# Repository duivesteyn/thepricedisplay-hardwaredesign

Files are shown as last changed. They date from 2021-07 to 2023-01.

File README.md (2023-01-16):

# thepricedisplay v2021 Hardware Design

Hardware Design and Data for making the price display hardware, pcb, case and general assembly.

Github repo created on 2021-07-11 in Adelaide.  

Also an awesome challenge, as I havent done a PCB or 3D printed before. 

Goal:
* Make initial batch of 10 price displays! See what I can get for the first few!!
* See if that works, then make 10 more!
* Unit cost needs to be less than $30!

# v2021 - First Iteration of the product** 

* The first thePriceDisplay screen with 6 items on display. 
* based upon Waveshare 2.9" ePaper Screen and an esp32 Dev Module.
* Operates on 115200 baud.

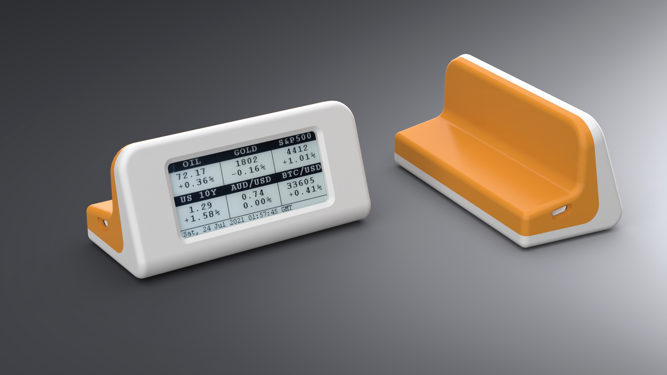
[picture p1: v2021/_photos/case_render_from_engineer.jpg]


## Design Concept
* Working Small Run Prototype
* Dev Board mounted onto custom PCB which does the translation for the wires to fit nicely. 
* No Battery. Was originally going to have a battery, however the dev boards with orthagonal JST battery connector are not available. I need the USB port to be on a seperate plain to the 2pin battery jst. (USB will extrude through case and JST should be internal). Oh well leave this for ver 2.

## BOM
| Part | Cost ea |
| ---| ---|
| waveshare screen (2.9") | $25 | 
| ESP Dev Board | $5 |
| 8 pin cable from screen to adapter board (8pin, PH (2.0) and 15cm long!) | $1 |
| Custom Adapter board PCB  ($30/10) | $3.1 |
| JST Connector which goes onto custom PCB (S8B-PH-SM4-TB) | $0.1 | 
| Case!!! | $15 |
| TOTAL | $75 |

## Assembly Instructions (v2021)
* Solder JST Connector and an 38pin ESP32 (FEIYANG) board together. See below Pins Connection for soldering guide.
* Test each connection between the JST and the ESP32 Pin!
* Prepare Case with Surface Finish and Paint!
    - Sand with 600+ grit wet/dry sandpaper, in water.
    - Use that Nice Plastic Conditioner
    - Install screen into top part of case. 

    - Connect PCB to Screen (lose PCB on ribbon cable.)
    - Program PCB with latest arduino code. Custom ID for each item! (TESTS SCREEN)
        - Serial port /dev/cu.usbserial-0001
        - Compile+upload. HOLD BOOT on BOARD for 2 secs when the Arduino Compiler says "Connecting........_____....._____." 
    - Install PCB Assembly into case. Scres are XYY and ABZ
    - Top Screen side screws:
    - Bottom Side screws: Self Tapper 1.5*4mm   with ORing below.
    - O Ring on bottom screws. (TYPE: OD2.5*0.5-20NB mm)
    - Load and stop on boot screen
    - Put in bag with USB cable.
    - Put sticker with logo on bag!

## v2021 Part Orders

BOM for 10 items:

| Part |Quantity Needed| Ordered/Have |
|---|---|---|
| Screens | 10 | 1 |
| PCB | 10 | 10 | 
| FEIYANG Board 38pin | 10 | 10 |
| PH2.0 Female Double head Connector 10cm Long, 8pin | 10 | 20 |
| JST Connector S8B-PH-SM4-TB | 20 | 20 |
| Screws 1.5mm x 5mm - Small End! (2.0mm hole) | 20 | 50 |
| Screws 2.6mm x 4mm - Screen and big end | 40 | 50 |
 
The 1.5mm (smaller) screws work great in a 2.0mm Diameter hole.
The 2.6mm screws work well in securing the screen, and the esp32 board.

## Pins Connection to Display 

The pins used on the esp32 Dev board to the Waveshare for working code are as follows:**

| Name | e-Paper Wire |  ESP32 Pin |
|---|---|---|
| VCC |  3.3V |  [Grey] |
| GND |  GND |  [Brown] |
| DIN |  GPIO14 |  [Blue] |
| CLK |  GPIO13 |  [Yellow]  |
| CS |  GPIO15 |  [Orange]  |
| DC |  GPIO27 |  [Green] |
| RST |  GPIO26 |  [White] |
| BUSY |  GPIO25 |  [Purple]  |

## Power Usage
* Sleeps most of the time. So its very power efficient.
* when updating it uses 0.04A (at 5V) using it for an hour on the PC consumed 13mah.
    - i.e. 17.5hrs of continual updating on a 700mah battery! which is only ~1-2% of the total cycle of the device! i.e. battery power is very effective.

## v2021 Device IDs
Schema: 8 digits. v1 starts with 1.
Backend DB setup for these devices!

#| n |  DeviceID  | Setup? |    Comment                          |
#|---|------------|--------|-------------------------------------|
#| T |  3b3a8397  |  ✅    | BMD Test Device                     |
#| 1 |  1a934f75  |  ✅    | READY TO GO!                        |
#| 2 |  14802ca3  |  ✅    | Gave to Gareth                      |
#| 3 |  1a49c43f  |  ✅    | Gave to Ben Broyd                   |
#| 4 |  19c4e9b5  |  ✅    | READY TO GO!                        |

# Manufacturing Notes

## Custom PCB Design Notes

Connects esp32 into a S8B-PH-SM4-TB connector. This flattens the overall design as no pins need to go vertically into the board.

Note: Font = OCR-A (same as what is used in fritzing)

PCB had a few revisions:
* ver 0.1 is my first PCB. Had a wrong connector pad. (Produced 10x)
* ver 0.2 is the one with the right connector pad. (Produced 10x)
* ver 0.3 has holes in the sides for use with Case designed with CAD engineer in August 2021.
* ver 0.4 has JST connector flipped 180deg. It reduces a fold in the cables.

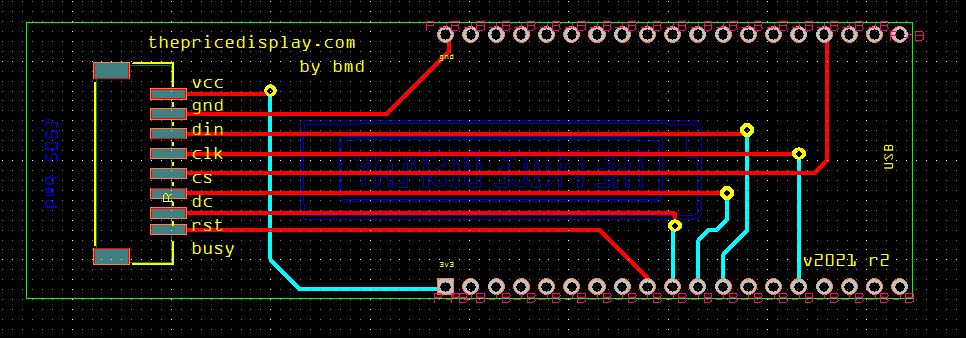
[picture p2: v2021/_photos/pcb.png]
 

## Case Design

* ver 0.0 is the version I made preemptively before I had the code working.
* ver 0.1 is the one the cad engineer made in August 2021. Designed by [janangachandima
](https://www.fiverr.com/janangachandima/design-any-enclosures-for-your-product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) on Fiverr.

## Lessons Learned
- Case too detailed. Had breakages in screw locations.
- Didnt factor in shipping etc.
- Self assembling takes forever.
- changedd color at last minute and so USB cable didnt match!

## ISSUES:
- Have ~3 boards that are bad and need reSOLDERING!!
- Have ~5 back cases that broke!!

# ROADMAP

* On Custom PCB! with esp32-wroom integrated into the board (And presoldered hopefully!!!)
* Supports battery backup
* Case design refined - better corners, and slimmer.
* PCB ver 0.4 have whole esp32 and connector on the same board!!
    * Use this [Schematic](https://learn.adafruit.com/huzzah32-esp32-breakout-board/downloads) or [This One](https://learn.adafruit.com/adafruit-huzzah32-esp32-feather/downloads)

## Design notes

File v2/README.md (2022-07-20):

# IDeas for V2!

- Design Version for Oil Price only!
- Get 3d model of device
- Create new case from 3mm acrylic sheets - and holes for screws
- Test 3d print in maker lab
- Layout pattern for laser cutter
    - Makerspace laser cutter is 720mm x 420mm
- Get screws and nuts.
- Integrate and refine
- Presets:
```
    AU: aid/usd, asx200, sap500, cba, bhp, qan
    USA: nasdaq, sap500, dow, 10y bond, aapl, goog
    UK: FTSE, other UK relevant stocks
    Oil: XOM, SLB, Hess, CvN, Brent, WTI
    Meme: TSLA, GME, AMC, Aark, COIN
    Crypto: BTC, Doge
    Gold : gold price,  top 5 biggest gold cos
    Gold AU: gold price, gold price au, newcrest, NST, WAF,
```
- Batch produce
- Render image for web! - Needs final case design. 3D Screenshot would be great!

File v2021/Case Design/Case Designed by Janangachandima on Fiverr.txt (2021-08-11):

Gig
https://www.fiverr.com/janangachandima/design-any-enclosures-for-your-product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

Link https://www.fiverr.com/v4/users/bend136i/orders/FO7197EB4F5C5?source=orders_navigator

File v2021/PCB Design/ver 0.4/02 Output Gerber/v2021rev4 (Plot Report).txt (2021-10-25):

Plot Report
-----------

Report Written:     Monday, September 20, 2021
Design Path:        C:\Users\Ben\Documents\GitHub\thepricedisplay-hardwaredesign\v2021\PCB Design\ver 0.4\01 DesignSpark PCB Work\v2021rev4.pcb
Design Title:       
Created:            6/08/2021 13:50:52
Last Saved:         20/09/2021 21:25:26
Editing Time:       601 min
Units:              mm (precision 0)

Device Settings
===============

Gerber Settings
===============

    Leading zero suppression.
    G01 assumed throughout.
    Line termination <*> <CR> <LF>.
    3.5 format absolute inches.

    Format commands defined in Gerber file.
    Aperture table defined in Gerber file.
    Hardware arcs allowed.

Plots Output
============

    Plot Job: "C:\Users\Ben\Documents\GitHub\thepricedisplay-hardwaredesign\v2021\PCB Design\ver 0.4\01 DesignSpark PCB Work\v2021rev4.mop"

Gerber Output
=============

C:\Users\Ben\Documents\GitHub\thepricedisplay-hardwaredesign\v2021\PCB Design\ver 0.4\01 DesignSpark PCB Work\v2021rev4 - Top Silkscreen.gbr

    Layers:
    ------------------
    Top Silkscreen
    Board Outlines

    D-Code Shape  (thou)
    -----------------------
    D10    Round 6.00
    D13    Round 1.00
    D25    Round 5.00

Gerber Output
=============

C:\Users\Ben\Documents\GitHub\thepricedisplay-hardwaredesign\v2021\PCB Design\ver 0.4\01 DesignSpark PCB Work\v2021rev4 - Top Paste.gbr

    Layers:
    -------------
    Top Paste

    D-Code Shape  (thou)
    -----------------------------------------------
    D14    Rectangle 56.70 X 131.70  Rotation 90
    D15    Rectangle 35.10 X 134.10  Rotation 90

Gerber Output
=============

C:\Users\Ben\Documents\GitHub\thepricedisplay-hardwaredesign\v2021\PCB Design\ver 0.4\01 DesignSpark PCB Work\v2021rev4 - Top Copper.gbr

    Layers:
    --------------
    Top Copper

    D-Code Shape  (thou)
    -----------------------------------------------
    D16    Round 15.00
    D17    Round 48.00
    D18    Rectangle 63.00 X 138.00  Rotation 90
    D19    Rectangle 39.00 X 138.00  Rotation 90
    D70    Round 61.42
    D71    Square 61.42

Gerber Output
=============

C:\Users\Ben\Documents\GitHub\thepricedisplay-hardwaredesign\v2021\PCB Design\ver 0.4\01 DesignSpark PCB Work\v2021rev4 - Top Resist.gbr

    Layers:
    --------------
    Top Resist

    D-Code Shape  (thou)
    -----------------------------------------------
    D20    Round 54.30
    D21    Rectangle 69.30 X 144.30  Rotation 90
    D22    Rectangle 45.30 X 144.30  Rotation 90
    D23    Round 67.72
    D24    Square 67.72

Gerber Output
=============

C:\Users\Ben\Documents\GitHub\thepricedisplay-hardwaredesign\v2021\PCB Design\ver 0.4\01 DesignSpark PCB Work\v2021rev4 - Bottom Copper.gbr

    Layers:
    -----------------
    Bottom Copper

    D-Code Shape  (thou)
    -----------------------
    D16    Round 15.00
    D17    Round 48.00
    D70    Round 61.42
    D71    Square 61.42

Gerber Output
=============

C:\Users\Ben\Documents\GitHub\thepricedisplay-hardwaredesign\v2021\PCB Design\ver 0.4\01 DesignSpark PCB Work\v2021rev4 - Bottom Silkscreen.gbr

    Layers:
    ---------------------
    Bottom Silkscreen
    Board Outlines

    D-Code Shape  (thou)
    -----------------------
    D13    Round 1.00
    D25    Round 5.00

Gerber Output
=============

C:\Users\Ben\Documents\GitHub\thepricedisplay-hardwaredesign\v2021\PCB Design\ver 0.4\01 DesignSpark PCB Work\v2021rev4 - Bottom Paste.gbr

    Layers:
    ----------------
    Bottom Paste

    D-Code Shape  (thou)
    -----------------------

Gerber Output
=============

C:\Users\Ben\Documents\GitHub\thepricedisplay-hardwaredesign\v2021\PCB Design\ver 0.4\01 DesignSpark PCB Work\v2021rev4 - Bottom Resist.gbr

    Layers:
    -----------------
    Bottom Resist

    D-Code Shape  (thou)
    -----------------------
    D20    Round 54.30
    D23    Round 67.72
    D24    Square 67.72

Gerber Output
=============

C:\Users\Ben\Documents\GitHub\thepricedisplay-hardwaredesign\v2021\PCB Design\ver 0.4\01 DesignSpark PCB Work\v2021rev4 - Documentation.gbr

    Layers:
    ------------------
    Documentation
    Board Outlines

    D-Code Shape  (thou)
    -----------------------
    D25    Round 5.00

Gerber Output
=============

C:\Users\Ben\Documents\GitHub\thepricedisplay-hardwaredesign\v2021\PCB Design\ver 0.4\01 DesignSpark PCB Work\v2021rev4 - Gerber Drill Data - [Through Hole].gbr

    Layers:
    ------------------
    [Through Hole]

    D-Code Shape  (thou)
    -----------------------
    D26    Round 24.00
    D27    Round 40.94

Gerber Output
=============

C:\Users\Ben\Documents\GitHub\thepricedisplay-hardwaredesign\v2021\PCB Design\ver 0.4\01 DesignSpark PCB Work\v2021rev4 - NC Drill Data - [Through Hole].gbr

    Layers:
    ------------------
    [Through Hole]

    D-Code Shape  (thou)
    -----------------------
    D26    Round 24.00
    D27    Round 40.94

Gerber Output
=============

plot.ger

    Layers:
    ------------------
    [Through Hole]

Drill Ident Drawing
===================

    Drill Plated Size Shape ID
    -----------------------------------
    24    Y      100  Round A
    41    Y      100  Round B

    D-Code Shape  (thou)
    -----------------------
    D25    Round 5.00
    D28    Round 100.00

End Of Report.

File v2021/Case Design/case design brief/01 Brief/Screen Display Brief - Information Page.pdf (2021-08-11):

## 䘀爀漀渀琀

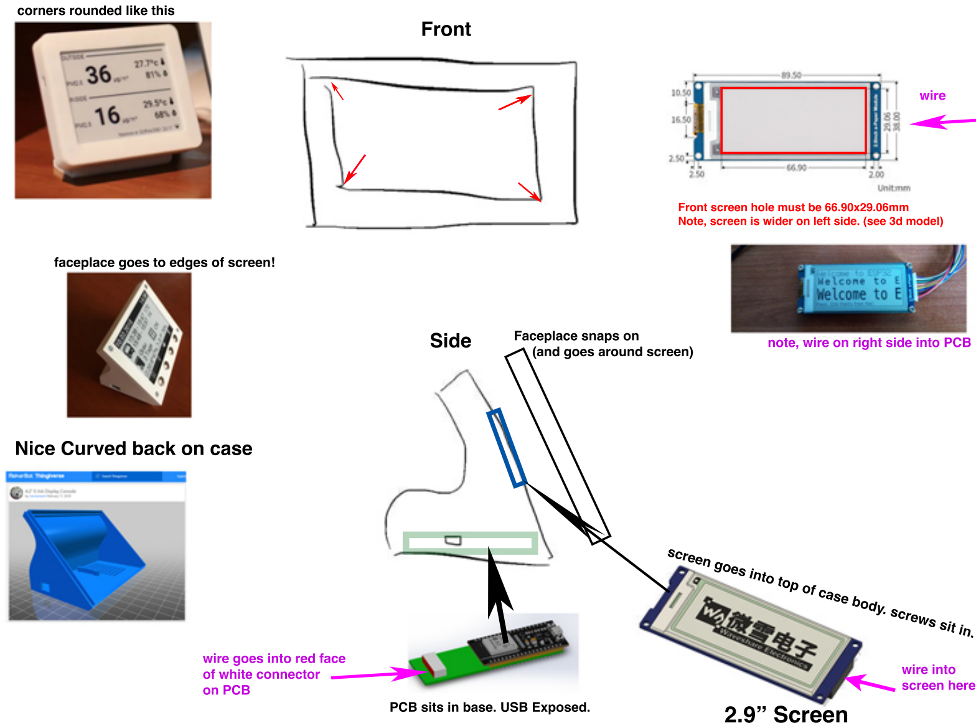
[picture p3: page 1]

## 一椀挀攀䌀甀爀瘀攀搀戀愀挀欀漀渀挀愀猀攀

## 匀椀搀攀

昀愀挀攀瀀氀愀挀攀最漀攀猀琀漀攀搀最攀猀漀昀猀挀爀攀攀渀℀

䘀愀挀攀瀀氀愀挀攀猀渀愀瀀猀漀渀
⠀愀渀搀最漀攀猀愀爀漀甀渀搀猀挀爀攀攀渀⤀

䘀爀漀渀琀猀挀爀攀攀渀栀漀氀攀洀甀猀琀戀攀㘀㘀⸀㤀　砀㈀㤀⸀　㘀洀洀 一漀琀攀Ⰰ猀挀爀攀攀渀椀猀眀椀搀攀爀漀渀氀攀昀琀猀椀搀攀⸀⠀猀攀攀㌀搀洀漀搀攀氀⤀

倀䌀䈀猀椀琀猀椀渀戀愀猀攀⸀唀匀䈀䔀砀瀀漀猀攀搀⸀

眀椀爀攀最漀攀猀椀渀琀漀爀攀搀昀愀挀攀
漀昀眀栀椀琀攀挀漀渀渀攀挀琀漀爀
漀渀倀䌀䈀

渀漀琀攀Ⰰ眀椀爀攀漀渀爀椀最栀琀猀椀搀攀椀渀琀漀倀䌀䈀

挀漀爀渀攀爀猀爀漀甀渀搀攀搀氀椀欀攀琀栀椀猀

眀椀爀攀

# ㈀⸀㤀ᴠ匀挀爀攀攀渀

### 猀挀爀攀攀渀最漀攀猀椀渀琀漀琀漀瀀漀昀挀愀猀攀戀漀搀礀⸀猀挀爀攀眀猀猀椀琀椀渀⸀

眀椀爀攀椀渀琀漀
猀挀爀攀攀渀栀攀爀攀

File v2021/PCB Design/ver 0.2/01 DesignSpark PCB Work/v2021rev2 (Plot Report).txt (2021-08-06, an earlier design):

Plot Report
-----------

Report Written:     Friday, August 06, 2021
Design Path:        C:\Users\Ben\Documents\GitHub\thepricedisplay-hardwaredesign\v2021\PCB Design\ver 0.2\01 DesignSpark PCB Work\v2021rev2.pcb
Design Title:       
Created:            6/08/2021 13:50:52
Last Saved:         6/08/2021 19:18:09
Editing Time:       318 min
Units:              mm (precision 0)

Device Settings
===============

Gerber Settings
===============

    Leading zero suppression.
    G01 assumed throughout.
    Line termination <*> <CR> <LF>.
    3.5 format absolute inches.

    Format commands defined in Gerber file.
    Aperture table defined in Gerber file.
    Hardware arcs allowed.

PDF Settings
============

Combine Plots Yes

Use Bookmarks Yes

Component Details Yes

Symbol Details Yes

Link Net Names Yes

View PDF Yes

All Colors Black No

Embed Fonts Yes

Plots Output
============

    Plot Job: "C:\Users\Ben\Documents\GitHub\thepricedisplay-hardwaredesign\v2021\PCB Design\ver 0.2\01 DesignSpark PCB Work\v2021rev2.mop"

PDF Output
==========

    Layer
    ---------------
    Top Silkscreen

PDF Output
==========

    Layer
    ----------
    Top Paste

PDF Output
==========

    Layer
    -----------
    Top Copper

PDF Output
==========

    Layer
    -----------
    Top Resist

PDF Output
==========

    Layer
    --------------
    Bottom Copper

PDF Output
==========

    Layer
    ------------------
    Bottom Silkscreen

PDF Output
==========

    Layer
    -------------
    Bottom Paste

PDF Output
==========

    Layer
    --------------
    Bottom Resist

PDF Output
==========

    Layer
    --------------
    Documentation

Gerber Output
=============

C:\Users\Ben\Documents\GitHub\thepricedisplay-hardwaredesign\v2021\PCB Design\ver 0.2\01 DesignSpark PCB Work\v2021rev2 - Gerber Drill Data - [Through Hole].gbr

    Layers:
    ------------------
    [Through Hole]

    D-Code Shape  (thou)
    -----------------------
    D26    Round 24.00
    D27    Round 40.94

Gerber Output
=============

C:\Users\Ben\Documents\GitHub\thepricedisplay-hardwaredesign\v2021\PCB Design\ver 0.2\01 DesignSpark PCB Work\v2021rev2 - NC Drill Data - [Through Hole].gbr

    Layers:
    ------------------
    [Through Hole]

    D-Code Shape  (thou)
    -----------------------
    D26    Round 24.00
    D27    Round 40.94

PDF Output
==========

    Layer
    ------

Drill Ident Drawing
===================

    Drill Plated Size Shape ID
    -----------------------------------
    1     Y      3    Round A
    1     Y      3    Round B

End Of Report.

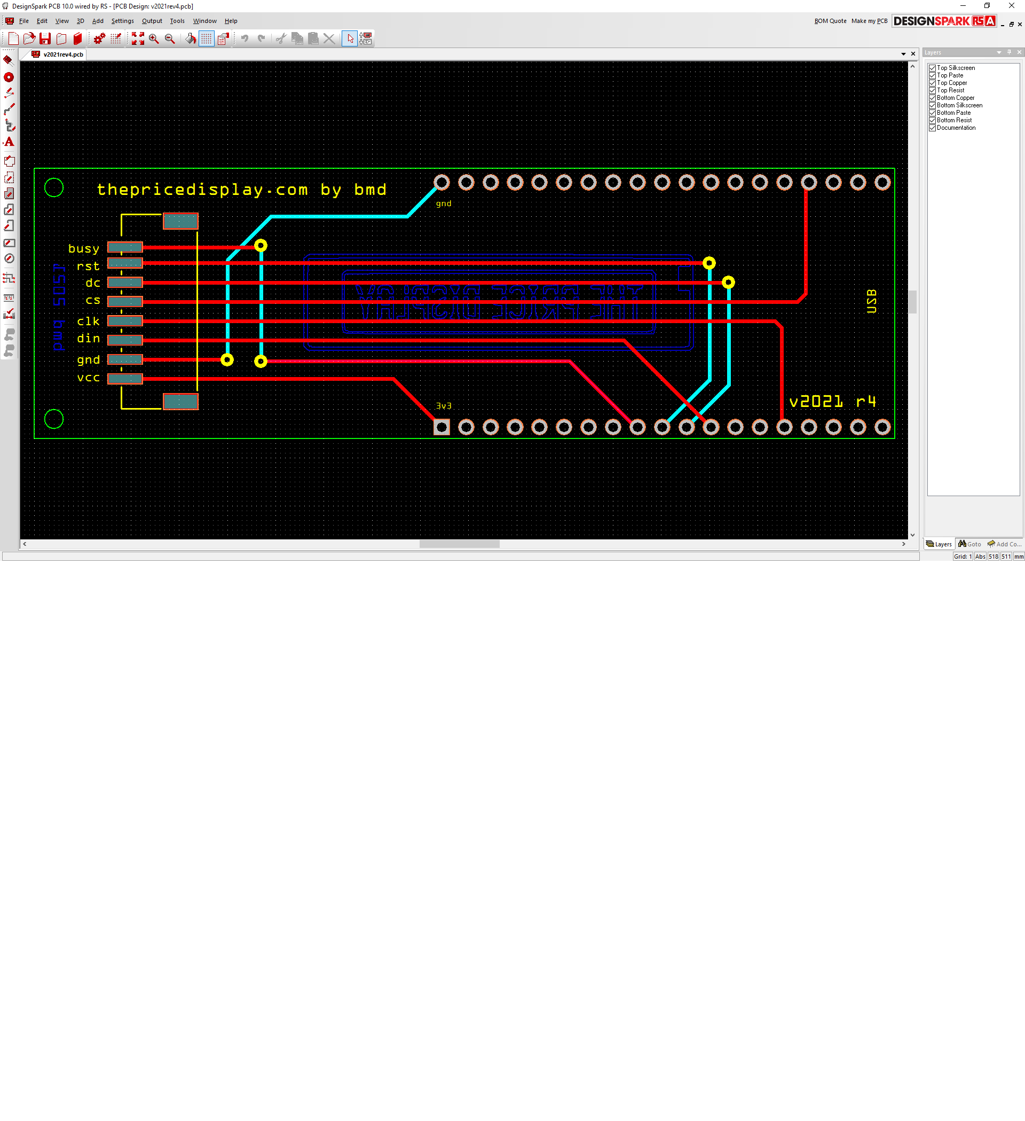
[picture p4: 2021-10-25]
v2021/PCB Design/ver 0.4/03 Screenshots of Final/pcb-2021-rev4.png

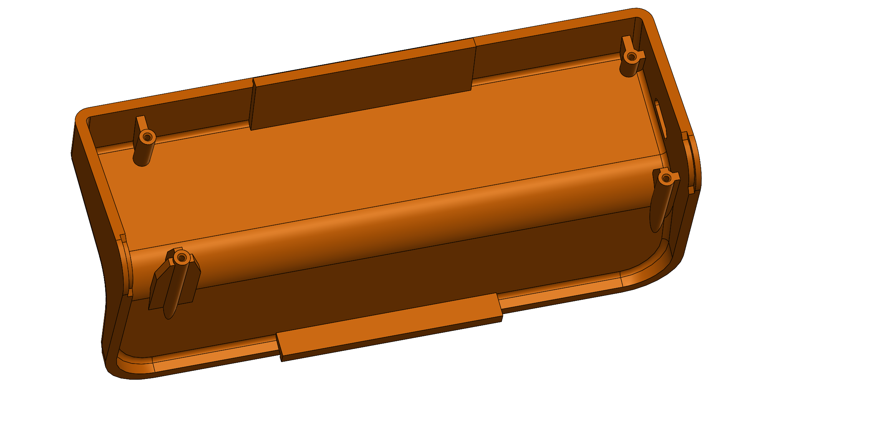
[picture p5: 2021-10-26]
v2021/Case Design/_Screenshots/2021-10-26 Back Redesign - image (2).png

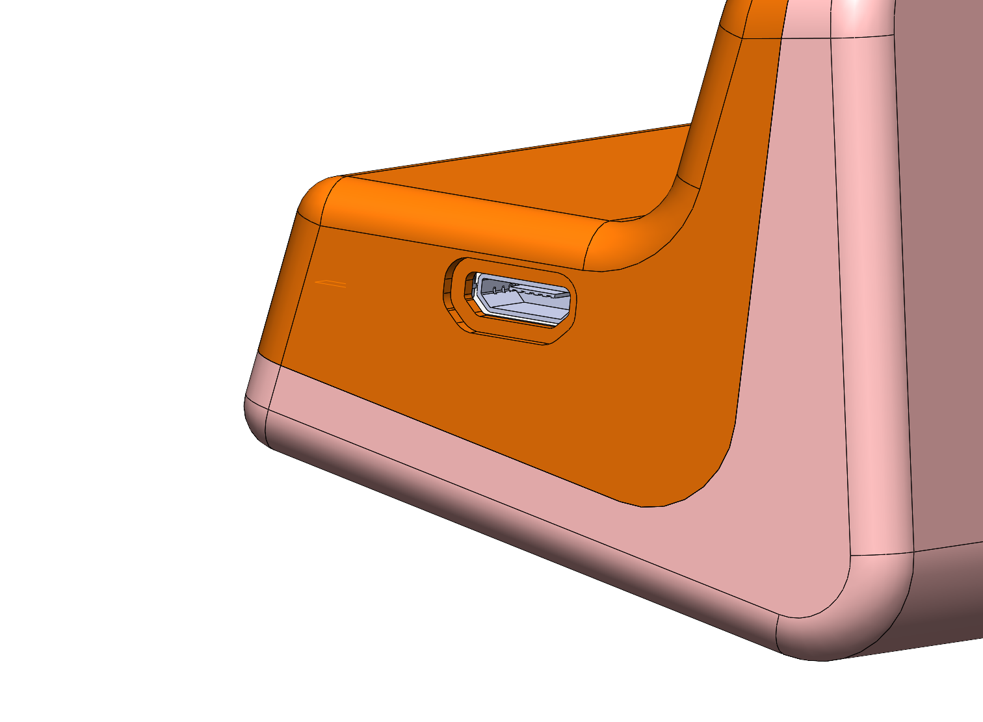
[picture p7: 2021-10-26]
v2021/Case Design/_Screenshots/2021-10-26 Back Redesign - image (1).png

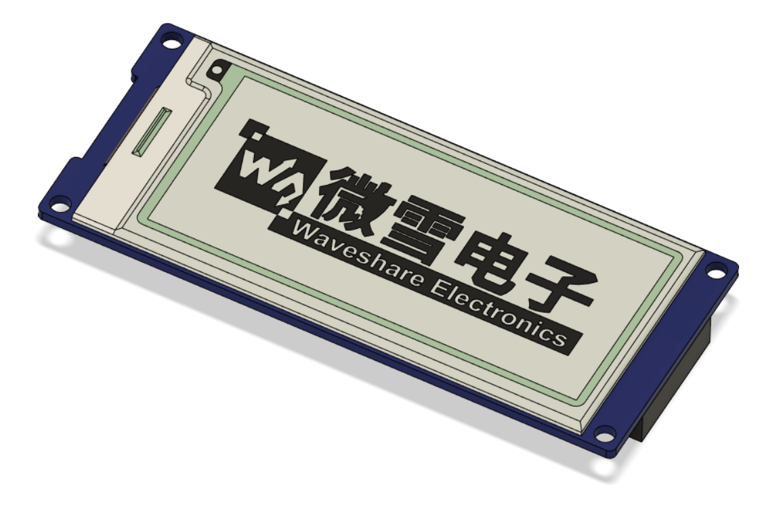
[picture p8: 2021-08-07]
v2021/Case Design/_parts/waveshare-2-9-e-paper-module-1.snapshot.1/Waveshare 2.9 epaper module.PNG

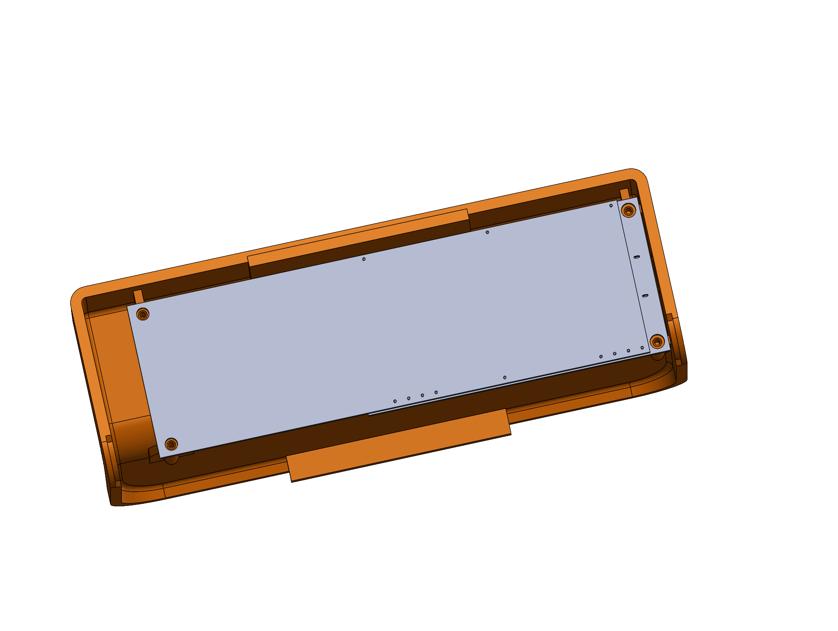
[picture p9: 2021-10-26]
v2021/Case Design/_Screenshots/2021-10-26 Back Redesign - image (4).png

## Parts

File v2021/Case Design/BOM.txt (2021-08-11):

M2.5
Self tapping screws
pan head type
Thread lenght = 3mm - 4mm
QTY (x2)

M1.5
Self tapping screws
pan head type
Thread lenght = 4mm - 6mm
QTY (x4)

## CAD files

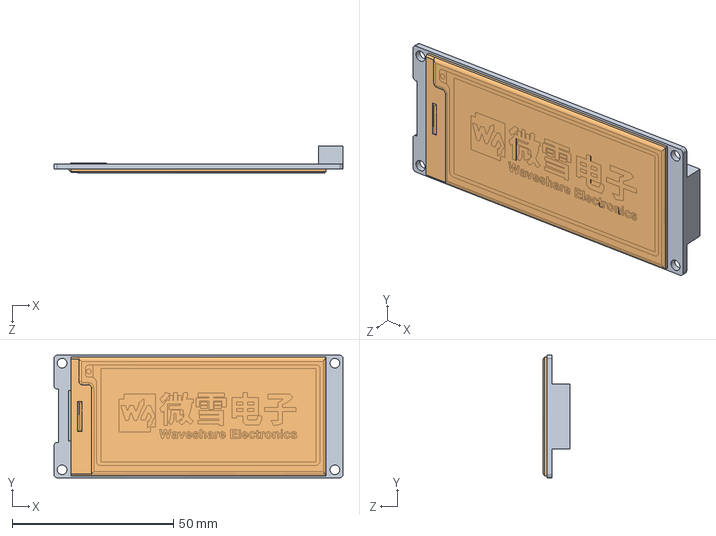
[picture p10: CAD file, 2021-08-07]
v2021/Case Design/_assembly/Waveshare 2.9 epaper module.SLDASM
89.5 x 38.0 x 8.47 mm
pcb
Waveshare 2.9 E-ink - Display Folded v1

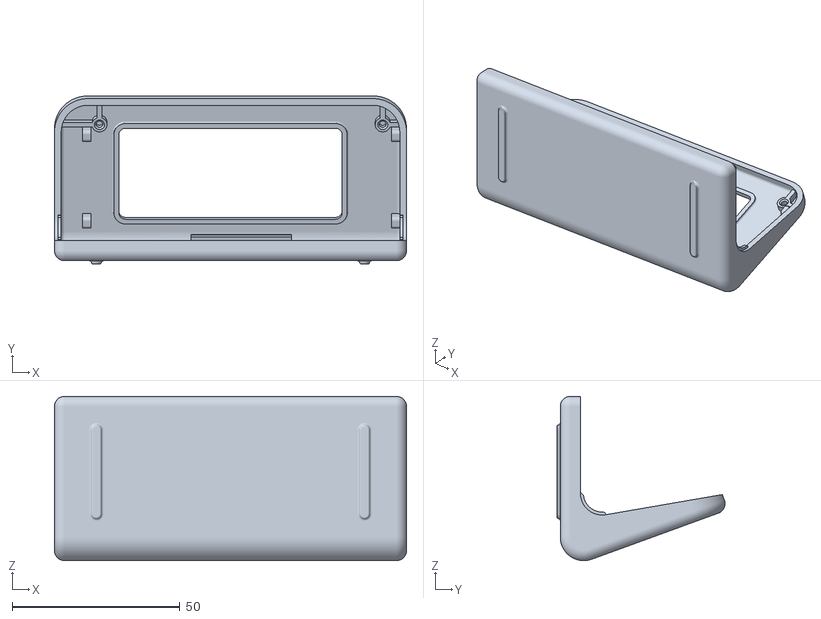
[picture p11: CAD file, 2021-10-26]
v2021/Case Design/_deliveries/02 2021-10-26 Modification of Back Panel/136 (st) 2.STL
105.0 x 50.2 x 49.0

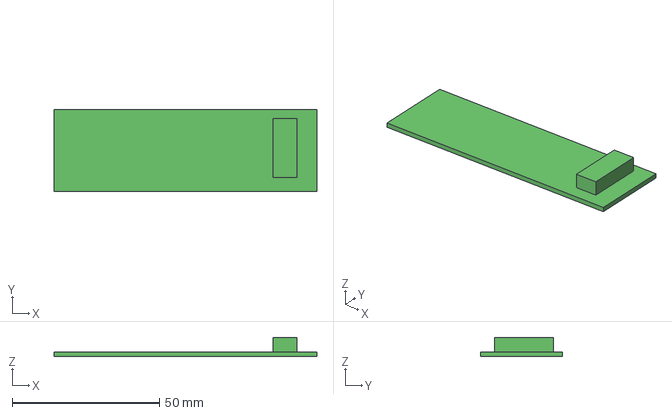
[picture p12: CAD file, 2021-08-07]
v2021/Case Design/_parts/mycustompcb/mycustompcb.stp
89.2 x 27.8 x 6.60 mm

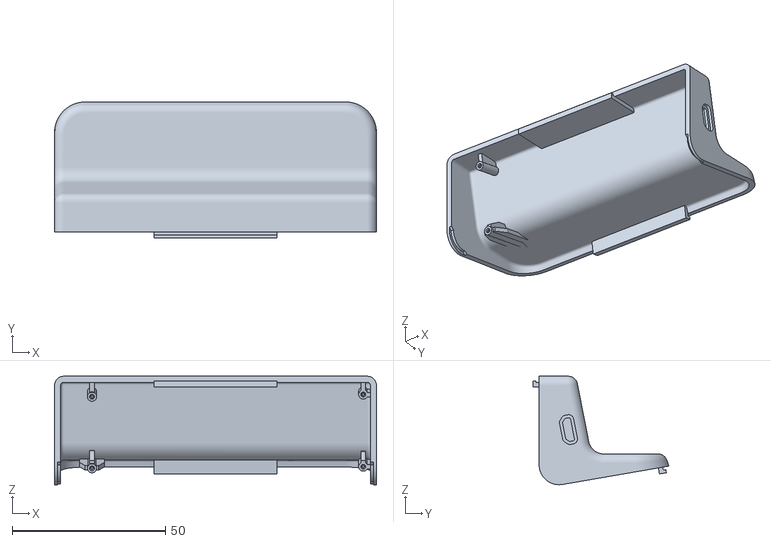
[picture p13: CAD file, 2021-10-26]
v2021/Case Design/_deliveries/02 2021-10-26 Modification of Back Panel/136 (st).STL
105.0 x 44.4 x 35.4

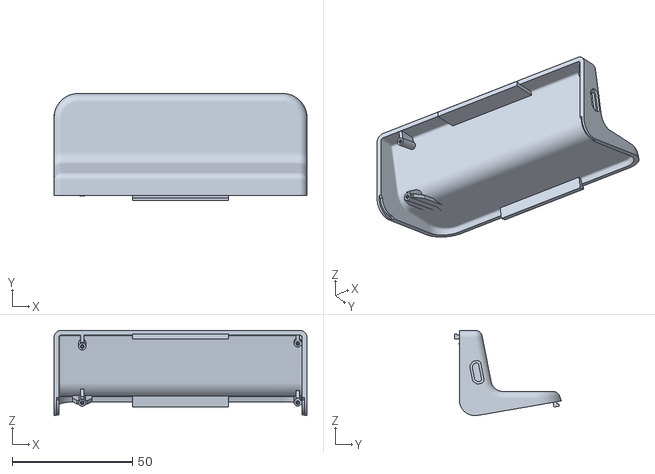
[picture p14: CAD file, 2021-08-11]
v2021/Case Design/Case Back (v2021).STL
105.0 x 44.4 x 35.4

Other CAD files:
v2021/Case Design/_assembly/Push_Bottom.sldprt
v2021/Case Design/_parts/_step_exports/WAVESHARE 2.9 EPAPER MODULE.STP
v2021/Case Design/_parts/waveshare-2-9-e-paper-module-1.snapshot.1/Waveshare 2.9 epaper module.step
v2021/Case Design/Case Body (v2021).STL
v2021/Case Design/_assembly/Led_red_0603.sldprt
v2021/Case Design/_assembly/Res_123.sldprt
v2021/Case Design/_assembly/MicroUSB.sldprt
v2021/Case Design/_assembly/pcb.sldprt
v2021/Case Design/_assembly/cp2102.sldprt
v2021/Case Design/_assembly/AMS1173.3V.sldprt
v2021/Case Design/_assembly/Cap_Tam_106C.sldprt
v2021/Case Design/_assembly/Part7solidworks.SLDPRT
v2021/Case Design/_assembly/Res_102.sldprt
v2021/Case Design/_assembly/Cap_0603.sldprt
v2021/Case Design/_assembly/Cap_Tam_106.sldprt
v2021/Case Design/_assembly/Res_471.sldprt
v2021/Case Design/_assembly/Res_512.sldprt
v2021/Case Design/_assembly/Transistor_smd.sldprt
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

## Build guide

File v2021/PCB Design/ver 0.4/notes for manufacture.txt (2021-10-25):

thepricedisplay pcb - rev3. should be final for v2021!
89mm x 28mm

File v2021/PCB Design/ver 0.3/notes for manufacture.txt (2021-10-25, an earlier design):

thepricedisplay pcb - rev3. should be final for v2021!
89mm x 28mm

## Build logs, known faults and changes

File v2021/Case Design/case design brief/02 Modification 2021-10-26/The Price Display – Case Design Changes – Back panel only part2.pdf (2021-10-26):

The Price Display – Case Design Changes – Back panel only part 2

5. The case doesn’t fully close as the pins on the board do not have enough space.

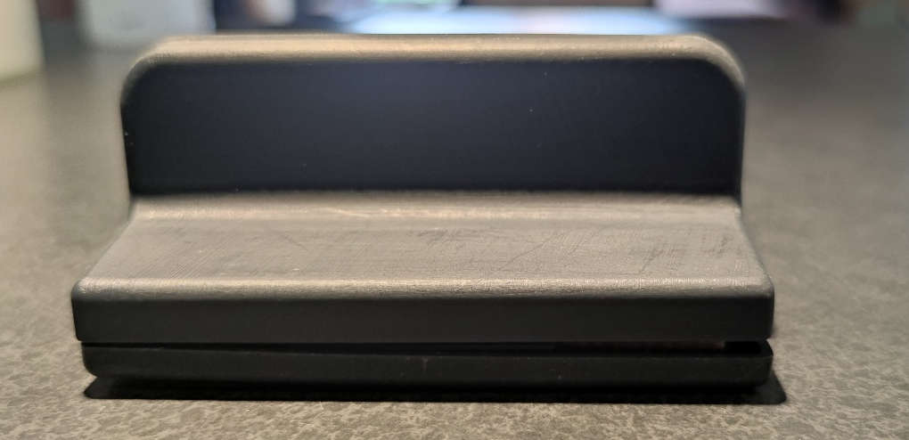
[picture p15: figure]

Pic 1: Back of case with circuit board inside. Note bottom right in pic is open.

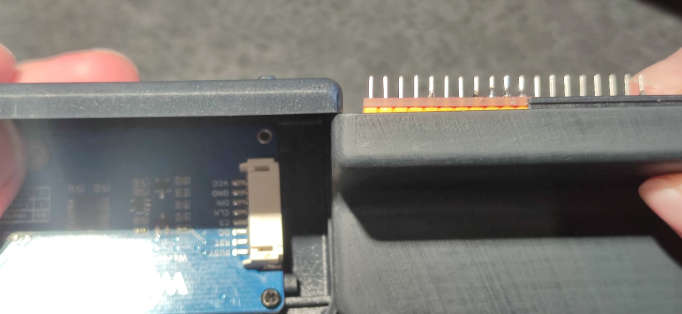
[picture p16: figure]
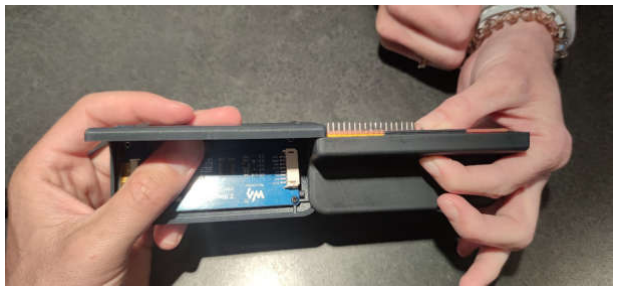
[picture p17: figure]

Pic 2A&B: I have lined up the two halves. See how the pins protrude past base of top case.

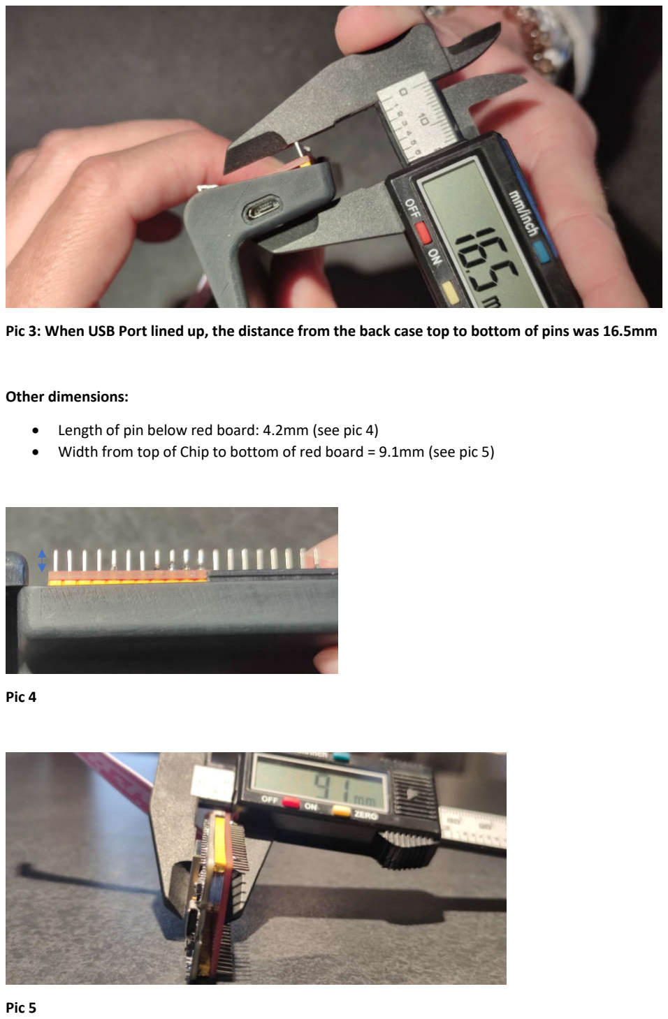
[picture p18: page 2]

Pic 3: When USB Port lined up, the distance from the back case top to bottom of pins was 16.5mm

Other dimensions:

- Length of pin below red board: 4.2mm (see pic 4)
- Width from top of Chip to bottom of red board = 9.1mm (see pic 5)

Pic 4

Pic 5

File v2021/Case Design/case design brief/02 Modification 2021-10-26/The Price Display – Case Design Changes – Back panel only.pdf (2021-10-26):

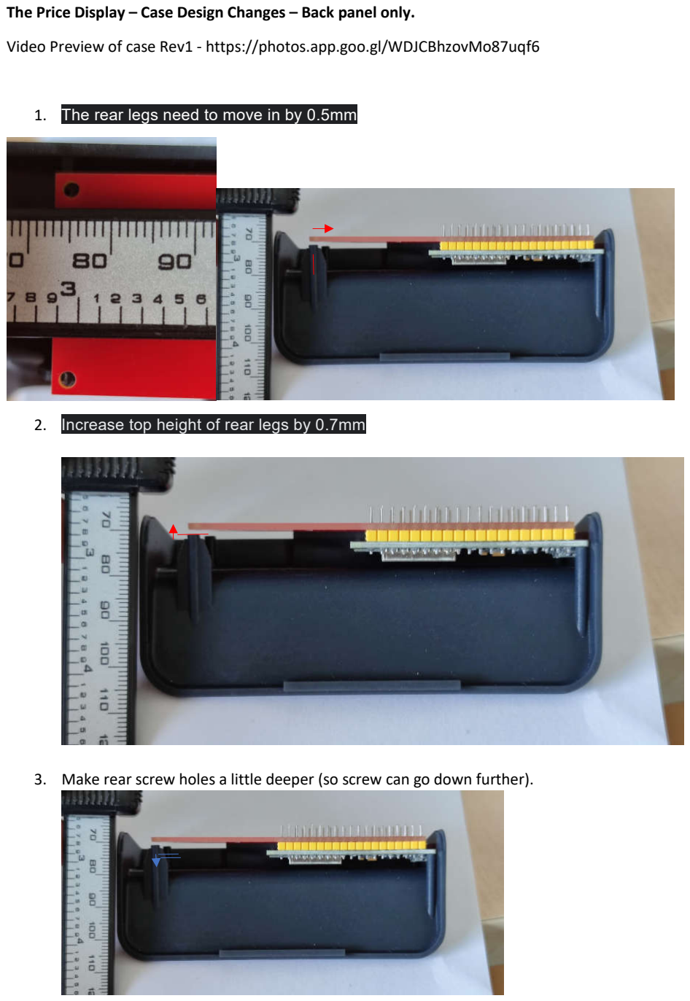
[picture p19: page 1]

The Price Display – Case Design Changes – Back panel only.

Video Preview of case Rev1 - https://photos.app.goo.gl/WDJCBhzovMo87uqf6

1. The rear legs need to move in by 0.5mm
2. Increase top height of rear legs by 0.7mm
3. Make rear screw holes a little deeper (so screw can go down further).

4. The holes for the inner centre point and size incorrect.

The computer chip (black board) holes were bigger than the 3D design provided.
The holes are 2.6mm in diameter, and the centre point is 2mm in from the corner. This caused the inner screw holes to not line up correctly.

I have taken a video of this interference https://photos.app.goo.gl/WDJCBhzovMo87uqf6

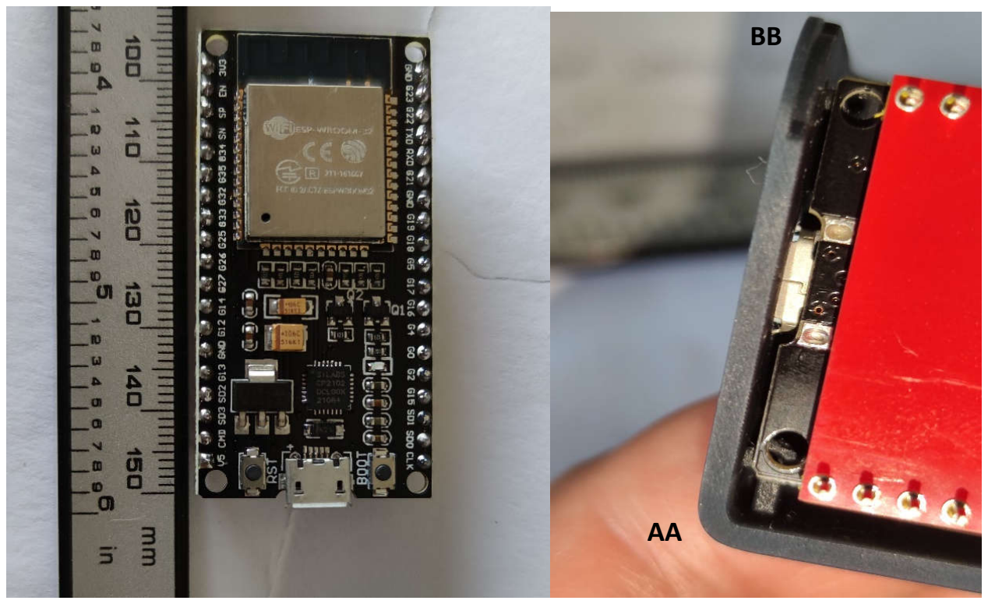
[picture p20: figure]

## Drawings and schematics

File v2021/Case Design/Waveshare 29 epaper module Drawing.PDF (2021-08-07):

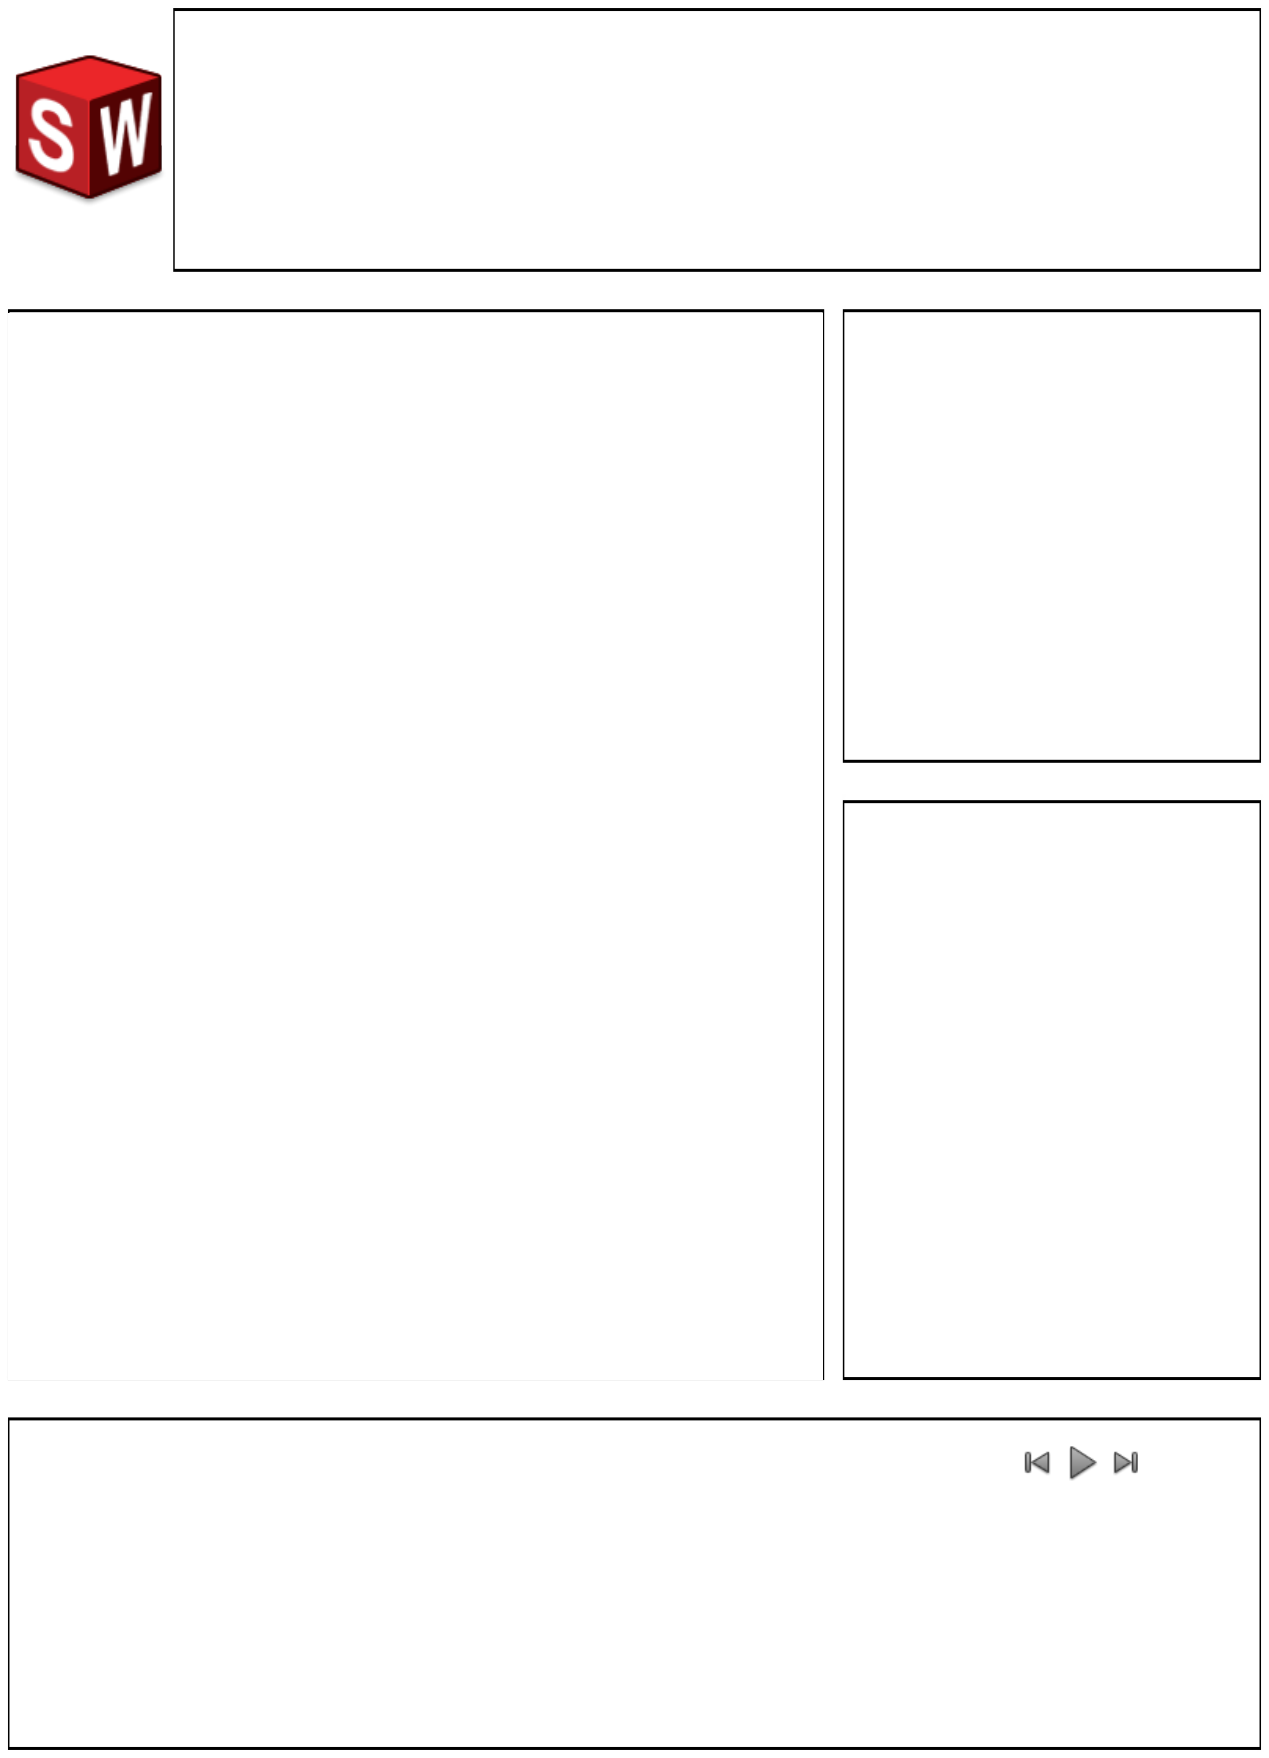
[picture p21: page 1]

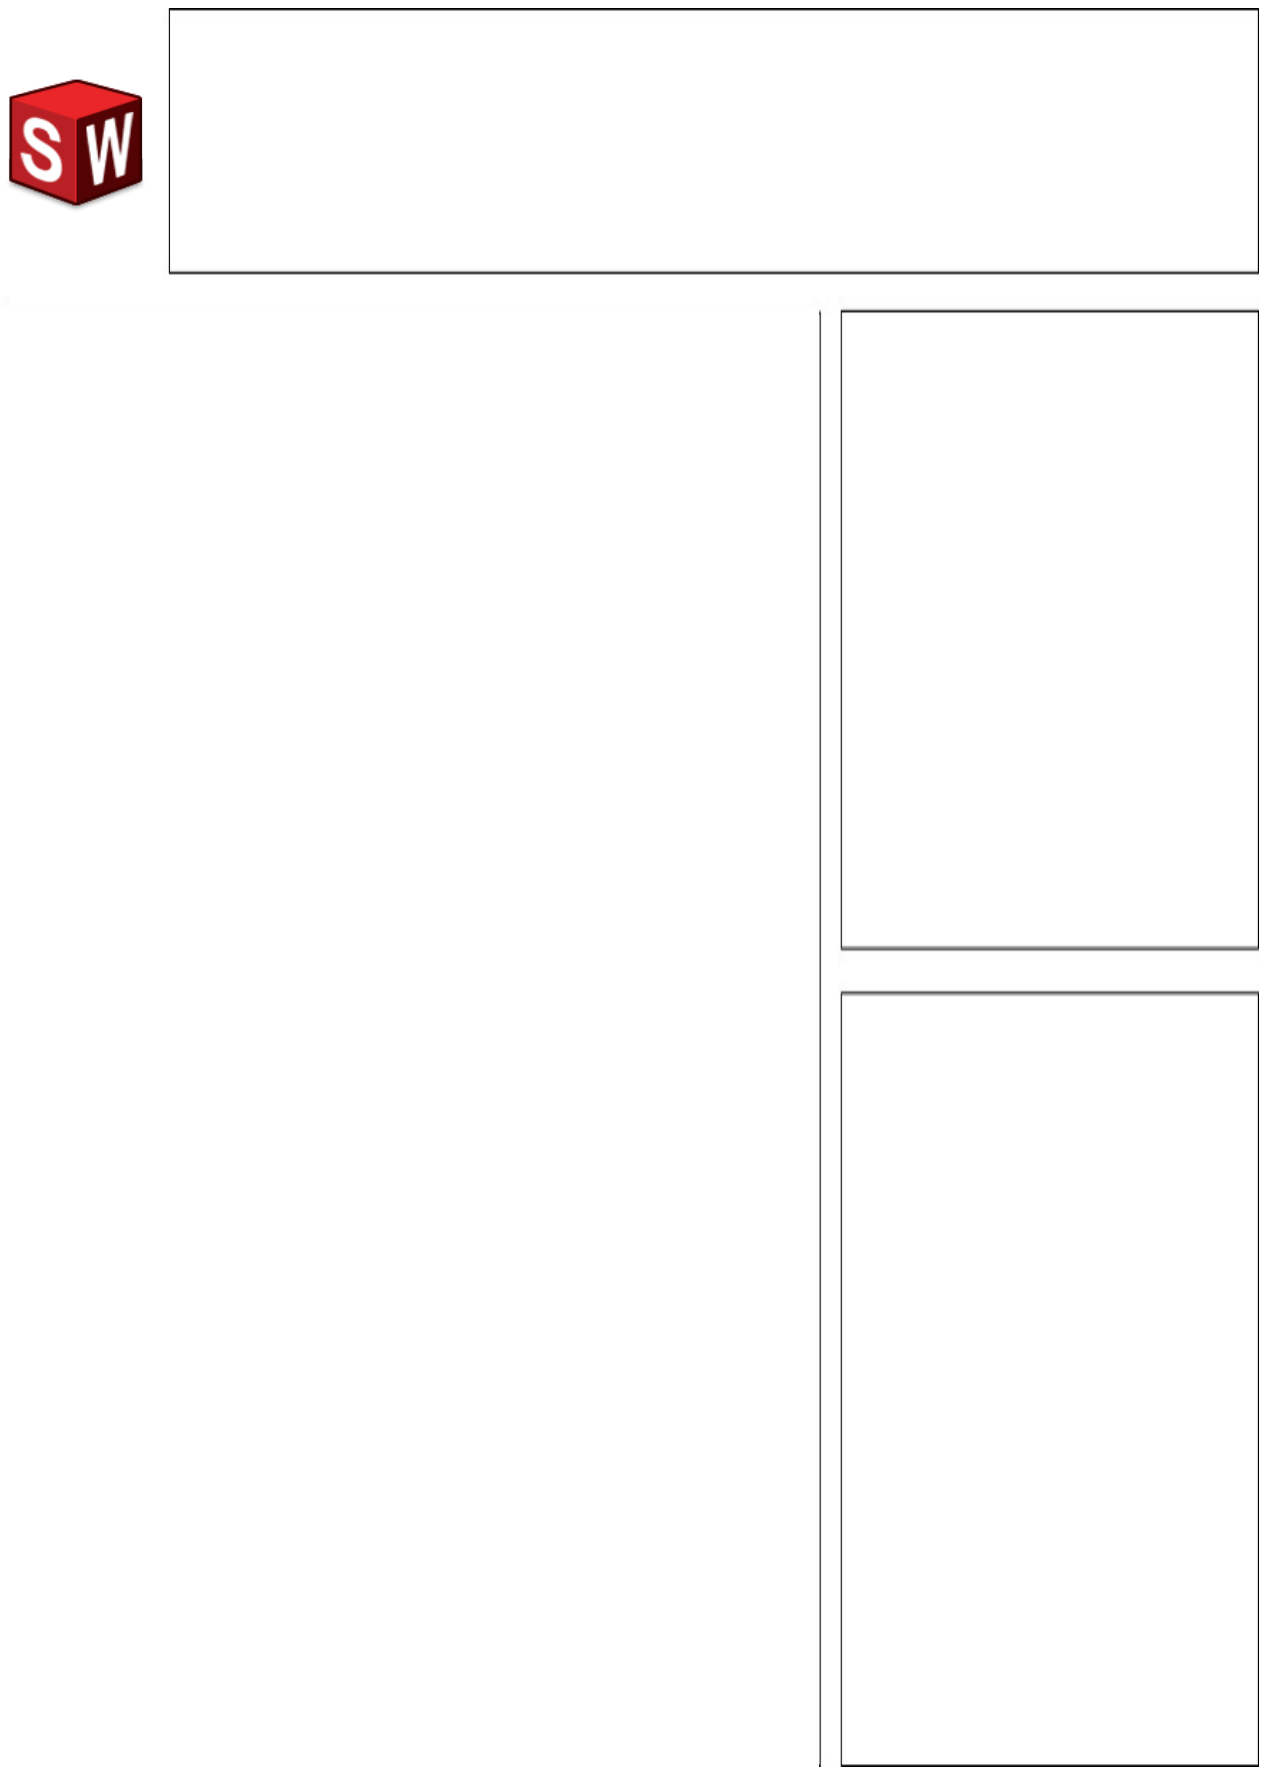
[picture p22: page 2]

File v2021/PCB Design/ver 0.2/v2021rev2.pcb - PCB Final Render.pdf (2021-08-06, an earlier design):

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

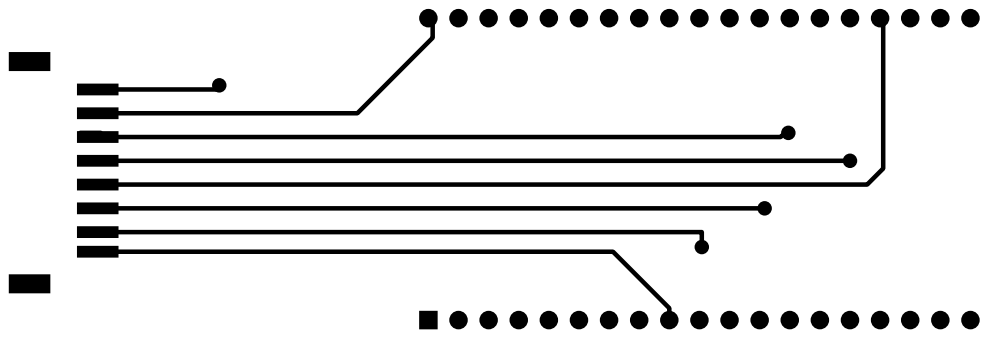
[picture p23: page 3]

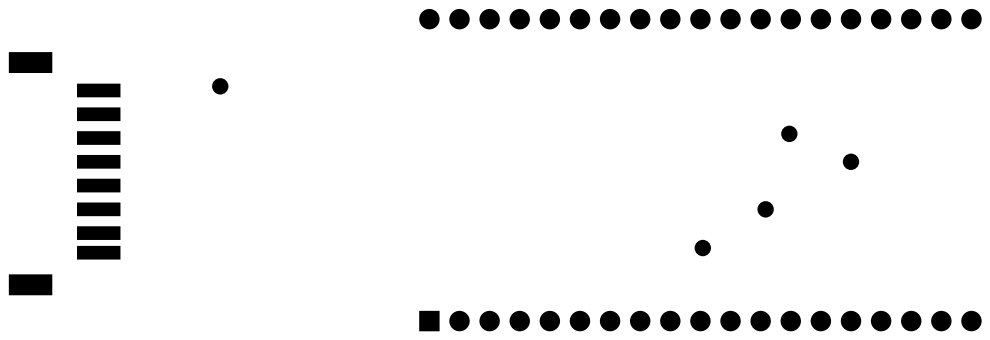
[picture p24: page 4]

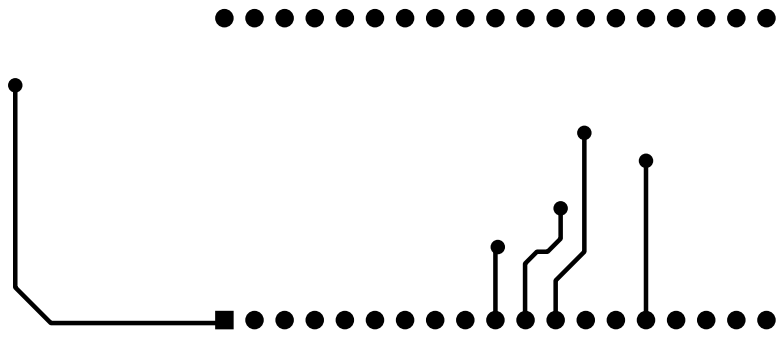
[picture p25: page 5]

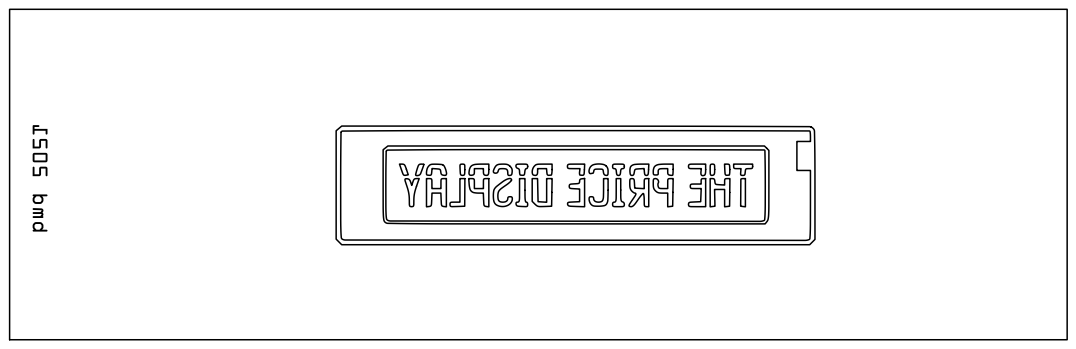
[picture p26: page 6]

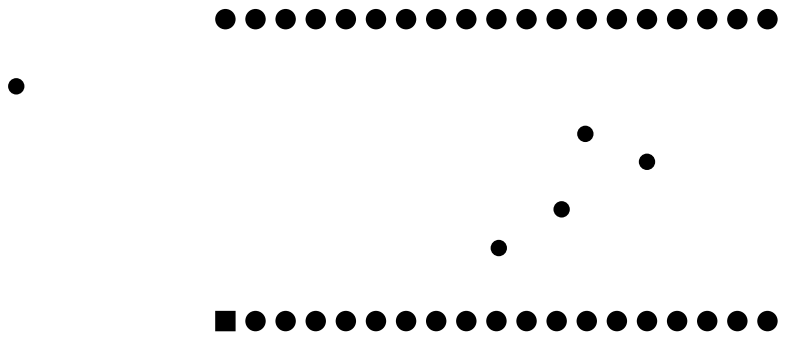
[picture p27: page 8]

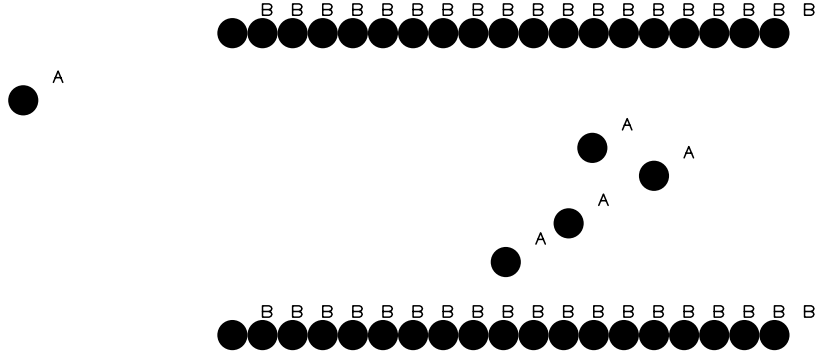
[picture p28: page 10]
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

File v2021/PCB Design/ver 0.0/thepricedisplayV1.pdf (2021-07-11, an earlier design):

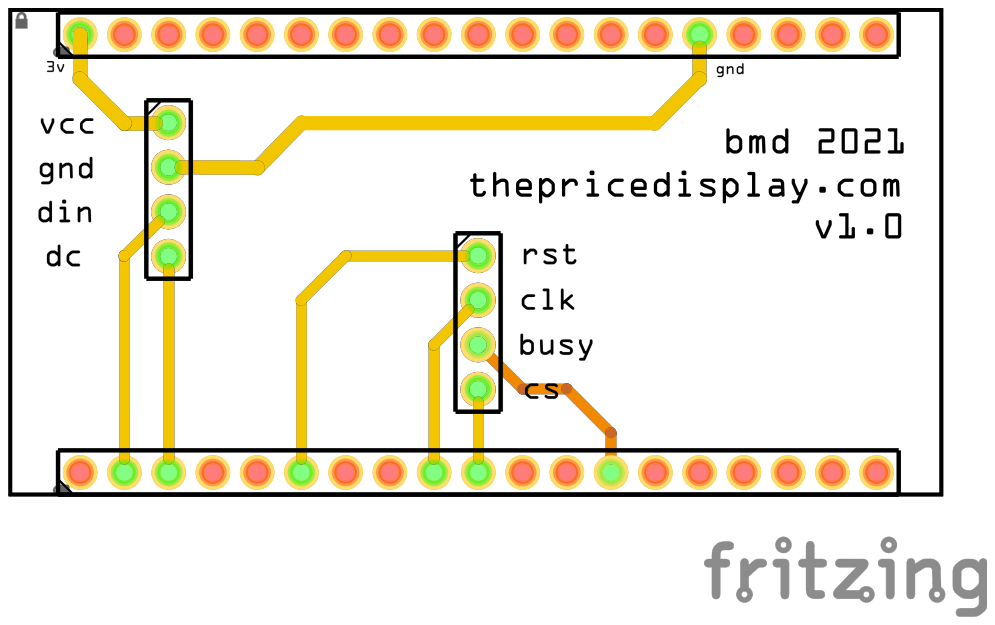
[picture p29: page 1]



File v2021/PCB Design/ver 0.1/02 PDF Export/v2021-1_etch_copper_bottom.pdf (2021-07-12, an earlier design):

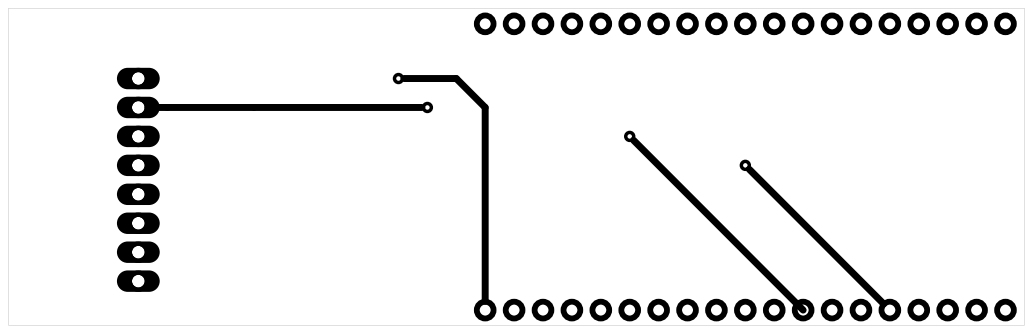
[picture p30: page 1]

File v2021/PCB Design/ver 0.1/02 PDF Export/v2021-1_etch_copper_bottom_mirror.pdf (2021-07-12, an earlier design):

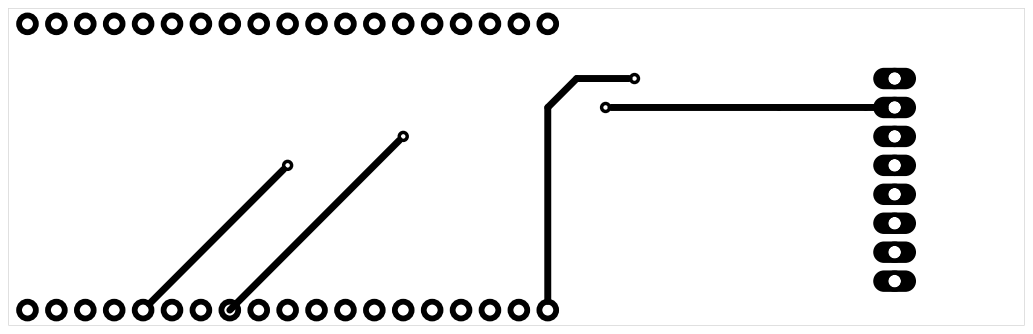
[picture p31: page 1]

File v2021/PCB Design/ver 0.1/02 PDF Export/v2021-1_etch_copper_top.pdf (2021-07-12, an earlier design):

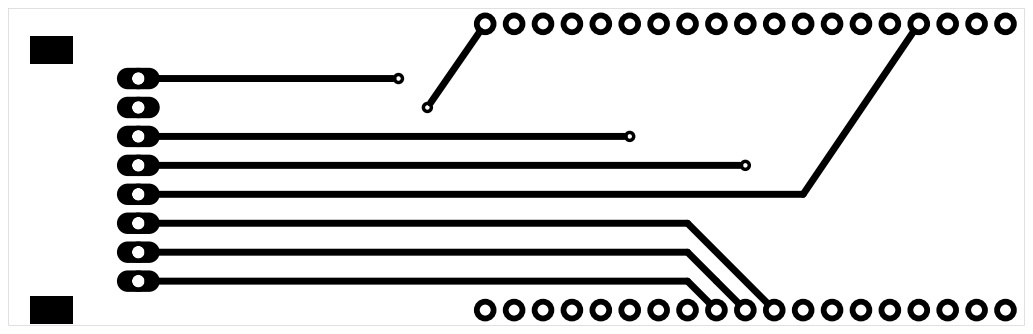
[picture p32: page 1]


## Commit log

2021-07-11 Adding data
    [20210314 Case-Bottom V1.stl, 20210314 Case-Top V1.stl, Untitled Sketch1.fzz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]
2021-07-12 PCB done for v2021
    [20210314 Case-Bottom V1.stl, 20210314 Case-Top V1.stl, Untitled Sketch1.fzz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]
2021-08-06 New PCB Design v2021 with proper footprints!
    [16548_The Price Display_NB_0.dxf, Untitled Sketch1.fzz, v2021-1.fzz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]
2021-08-07 Parts Prepared in STEP
    Screen and PCB Assembly!
    [20210314 Case-Bottom V1.stl, 20210314 Case-Top V1.stl, AMS1173.3V.sldprt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]
2021-08-11 Case Received from Designer
    [Case Back (v2021).STL, Case Body (v2021).STL]
2021-08-16 Documentation and updated pcb rev3. Waiting on Rev 2 before I get rev3 manufactured.
    - Added images
    - Updated notes for hardware
    - Up
2021-10-25 ver 0.4 pcb and notes about screws in design.
    [v2021rev3 - Bottom Copper.gbr, v2021rev3 - Bottom Paste.gbr, v2021rev3 - Bottom Resist.gbr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]
2021-10-26 New Back Case
    Fixed 4x PCB Location issues and pin height issue.
    [136 (st) 2.STL, 136 (st).STL, WAVESHARE 2.9 EPAPER MODULE.STP]
2023-01-16 Added who I gave devices to
